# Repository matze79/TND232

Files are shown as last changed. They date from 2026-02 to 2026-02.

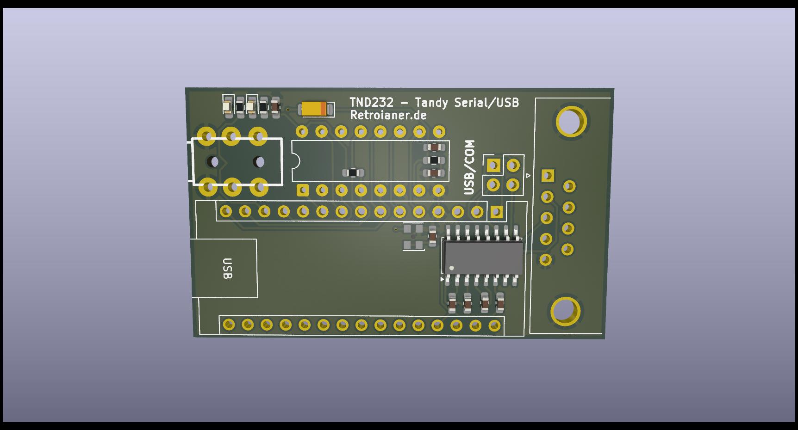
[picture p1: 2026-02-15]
Hardware/SMD/Tandy SMD.jpg

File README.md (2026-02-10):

📢 Project: TND232 – RS232 & USB SN76489 Tandy Sound Card

Home Project Site: https://www.retroianer.de

TND232 is a retro-computing hardware and software project to bring authentic Tandy/PCjr style 3-voice sound to IBM-PC compatible computers using modern interfaces like RS232 (serial) and USB, driven by the classic Texas Instruments SN76489 programmable sound generator chip.

🎯 Overview

Many classic DOS games support the Tandy 1000’s 3-voice audio produced by the SN76489 sound chip, but modern vintage add-ons like ISA boards aren’t always practical for newer PCs or laptops without expansion slots. The TND232 project provides an interface to control an SN76489 sound generator externally:

Serial (RS232) interface – connect via the PC’s COM port

USB interface – USB-powered control for systems without RS232

Drives an SN76489 sound module (3 square waves + noise) for authentic sound output on classic software

Includes DOS drivers/utilities to support music and game sound

The goal is to offer a flexible, cross-platform way to add real retro sound hardware to DOS machines without needing an ISA expansion card, while preserving authentic Tandy audio for games and demos.

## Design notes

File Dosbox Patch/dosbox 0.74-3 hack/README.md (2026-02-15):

DOSBox 0.74.3 – Serial Port Hack

This repository contains a modified File of DOSBox 0.74.3 with the serial device hardcoded in the source.

⚠️ Warning:

This is not a proper DOSBox serial implementation.

It is only a quick hack to make serial communication work in a limited way.

Serial Port Configuration

Edit the serial device directly in the source code.

Example devices:

Linux USB serial #1:

/dev/ttyUSB0

Adjust the device path as needed for your system.

Replace the modified file in the DOSBox 0.74.3 source tree.

Build \& Install

Install into a separate prefix to avoid conflicts.

./configure --prefix=/opt/dosbox-tandyserial

make

make install

Platform Status

NetBSD code - tested only on NetBSD 10.1 / sparc64 

Limitations

Experimental / hacky

Not upstream-ready

Minimal functionality only

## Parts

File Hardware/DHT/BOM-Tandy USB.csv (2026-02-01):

Comment | Designator | Footprint | LCSC | Quantity
2,2K | R4 | R_Axial_DIN0207_L6.3mm_D2.5mm_P10.16mm_Horizontal |  | 1
XO32 | Y3 | Oscillator_SMD_EuroQuartz_XO32-4Pin_3.2x2.5mm |  | 1
SG-7050CCN | Y2 | Oscillator_SMD_SeikoEpson_SG8002CA-4Pin_7.0x5.0mm |  | 1
DE9_Socket_MountingHoles | J3 | DSUB-9_Socket_Horizontal_P2.77x2.84mm_EdgePinOffset4.94mm_Housed_MountingHolesOffset4.94mm |  | 1
LED | D1 | LED_D3.0mm |  | 1
LED | D2 | LED_D3.0mm |  | 1
100nf | C9 | C_Disc_D3.4mm_W2.1mm_P2.50mm |  | 1
10uf | C6 | CP_Radial_D5.0mm_P2.50mm |  | 1
100nf | C8 | C_Disc_D3.4mm_W2.1mm_P2.50mm |  | 1
10uf | C7 | CP_Radial_D5.0mm_P2.50mm |  | 1
100nf | C2 | C_Disc_D3.4mm_W2.1mm_P2.50mm |  | 1
SN76489AN | U1 | DIP-16_W7.62mm |  | 1
10uf | C5 | CP_Radial_D5.0mm_P2.50mm |  | 1
3.579 Mhz | Y1 | Oscillator_DIP-14 |  | 1
10uf | C4 | CP_Radial_D5.0mm_P2.50mm |  | 1
33R | R1 | R_Axial_DIN0207_L6.3mm_D2.5mm_P10.16mm_Horizontal |  | 1
100uf | C3 | CP_Radial_D5.0mm_P2.50mm |  | 1
68pf | C1 | C_Disc_D3.4mm_W2.1mm_P2.50mm |  | 1
AudioJack3 | J1 | jack_3.5_pj313d-smt |  | 1
330R | R2 | R_Axial_DIN0207_L6.3mm_D2.5mm_P10.16mm_Horizontal |  | 1
330R | R3 | R_Axial_DIN0207_L6.3mm_D2.5mm_P10.16mm_Horizontal |  | 1
MAX232 | U2 | DIP-16_W7.62mm_LongPads |  | 1
Arduino_Nano_v3.x | A1 | Arduino_Nano |  | 1

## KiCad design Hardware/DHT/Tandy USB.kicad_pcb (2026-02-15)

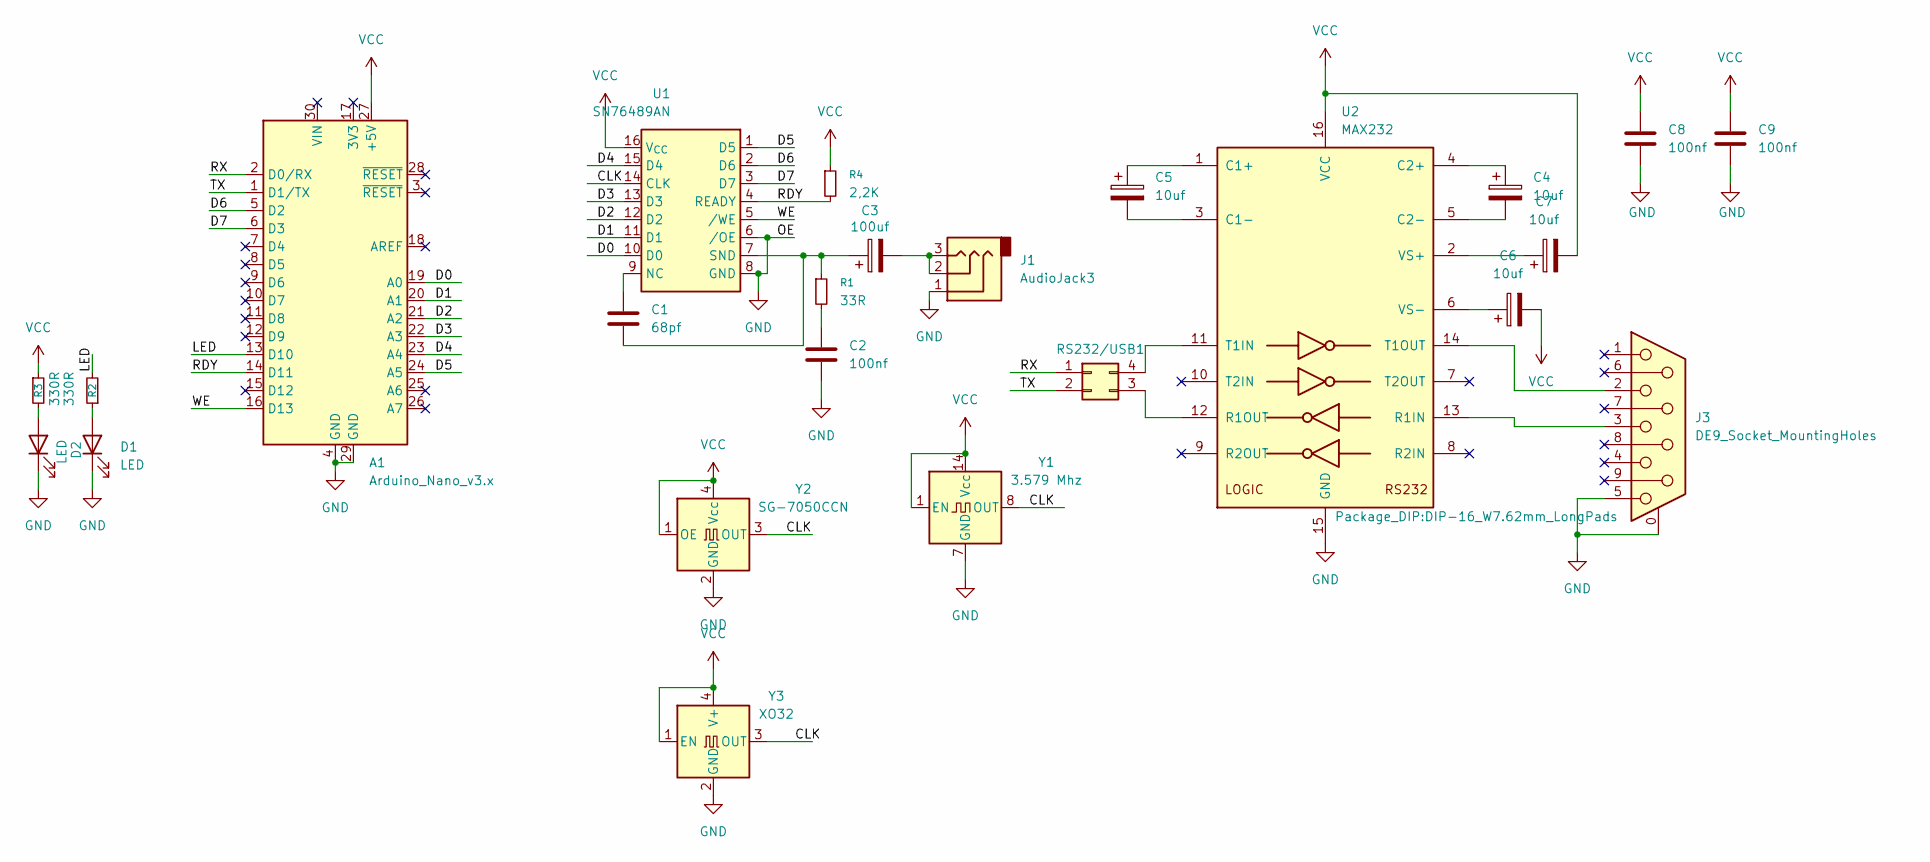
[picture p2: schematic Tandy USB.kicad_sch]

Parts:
A1: Arduino_Nano_v3.x; Arduino_Nano
C1: 68pf; C_Disc_D3.4mm_W2.1mm_P2.50mm
C2, C8, C9: 100nf; C_Disc_D3.4mm_W2.1mm_P2.50mm
C3: 100uf; CP_Radial_D5.0mm_P2.50mm
C4, C5, C6, C7: 10uf; CP_Radial_D5.0mm_P2.50mm
D1, D2: LED; LED_D3.0mm
J1: AudioJack3; jack_3.5_pj313d-smt
J3: DE9_Socket_MountingHoles; DSUB-9_Socket_Horizontal_P2.77x2.84mm_EdgePinOffset4.94mm_H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
R1: 33R; R_Axial_DIN0207_L6.3mm_D2.5mm_P10.16mm_Horizontal
R2, R3: 330R; R_Axial_DIN0207_L6.3mm_D2.5mm_P10.16mm_Horizontal
R4: 2,2K; R_Axial_DIN0207_L6.3mm_D2.5mm_P10.16mm_Horizontal
RS232/USB1: Conn_02x02_Counter_Clockwise; PinHeader_2x02_P2.54mm_Vertical
U1: SN76489AN; DIP-16_W7.62mm
U2: MAX232; DIP-16_W7.62mm_LongPads
Y1: 3.579 Mhz; Oscillator_DIP-14
Y2: SG-7050CCN; Oscillator_SMD_SeikoEpson_SG8002CA-4Pin_7.0x5.0mm
Y3: XO32; Oscillator_SMD_EuroQuartz_XO32-4Pin_3.2x2.5mm

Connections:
/CLK: U1.14 (CLK), Y1.8 (OUT), Y2.3 (OUT), Y3.3 (OUT)
/D0: A1.19 (A0), U1.10 (D0)
/D1: A1.20 (A1), U1.11 (D1)
/D2: A1.21 (A2), U1.12 (D2)
/D3: A1.22 (A3), U1.13 (D3)
/D4: A1.23 (A4), U1.15 (D4)
/D5: A1.24 (A5), U1.1 (D5)
/D6: A1.5 (D2), U1.2 (D6)
/D7: A1.6 (D3), U1.3 (D7)
/LED: A1.13 (D10), R2.2
/RDY: A1.14 (D11), R4.2, U1.4 (READY)
/RX: A1.2 (D0/RX), RS232/USB1.1
/TX: A1.1 (D1/TX), RS232/USB1.2
/WE: A1.16 (D13), U1.5 (/WE)
GND: A1.4 (GND), A1.29 (GND), C2.1, C8.1, C9.1, D1.1 (K), D2.1 (K), J1.1, J3.0 (PAD), J3.5, U1.6 (/OE), U1.8 (GND), U2.15 (GND), Y1.7 (GND), Y2.2 (GND), Y3.2 (GND)
unnamed: C2.2, R1.2
unnamed: C3.2, J1.2, J1.3
unnamed: D1.2 (A), R2.1
unnamed: D2.2 (A), R3.2
unnamed: RS232/USB1.3, U2.12 (R1OUT)
unnamed: RS232/USB1.4, U2.11 (T1IN)
unnamed: C1.2, U1.9 (NC)
unnamed: C1.1, C3.1, R1.1, U1.7 (SND)
unnamed: C5.1, U2.1 (C1+)
unnamed: C5.2, U2.3 (C1-)
unnamed: C4.1, U2.4 (C2+)
unnamed: C4.2, U2.5 (C2-)
unnamed: J3.3, U2.13 (R1IN)
unnamed: J3.2, U2.14 (T1OUT)
unnamed: C7.1, U2.2 (VS+)
unnamed: C6.1, U2.6 (VS-)
VCC: A1.27 (+5V), C6.2, C7.2, C8.2, C9.2, R3.1, R4.1, U1.16 (V_{CC}), U2.16 (VCC), Y1.1 (EN), Y1.14 (Vcc), Y2.1 (OE), Y2.4 (Vcc), Y3.1 (EN), Y3.4 (V+)

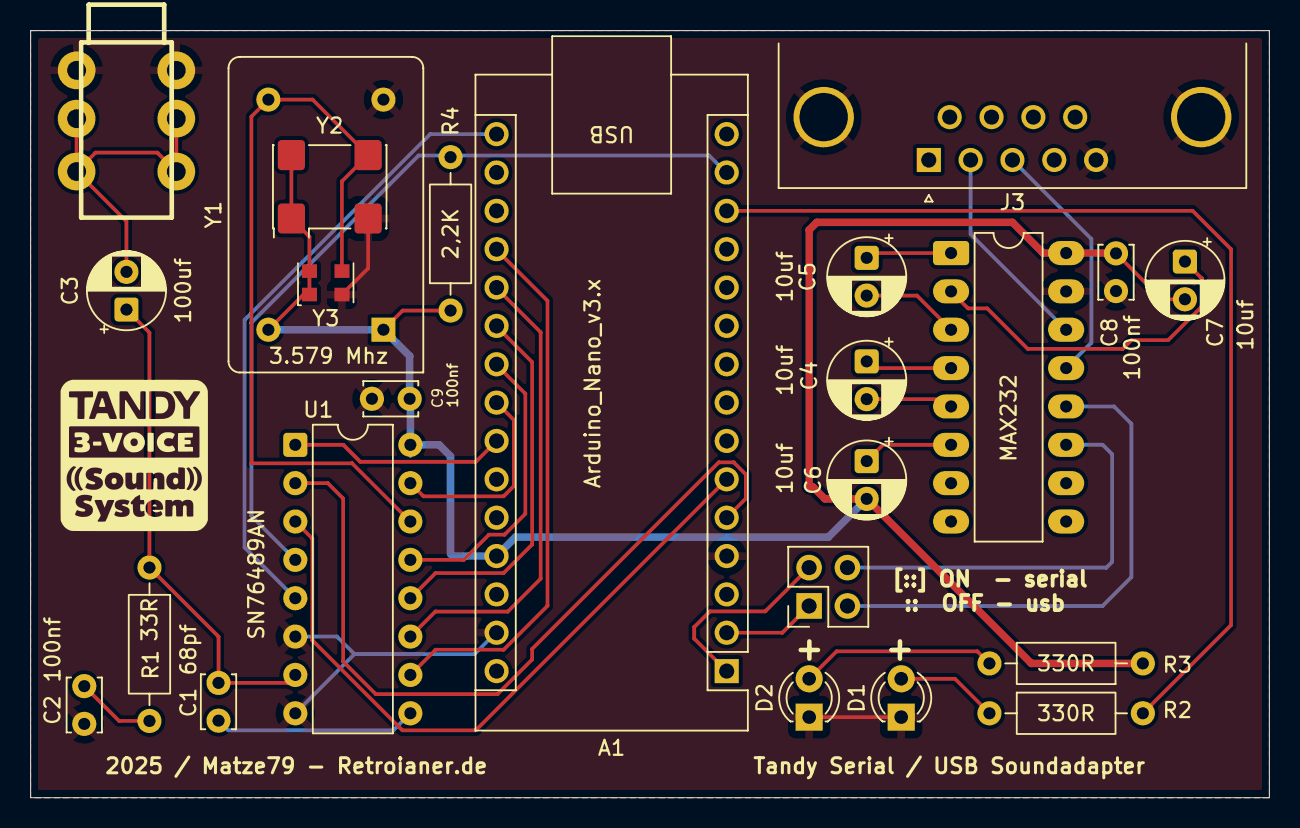
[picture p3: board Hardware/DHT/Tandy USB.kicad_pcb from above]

Board: 2 copper layers, 82.0 x 50.8 mm, 24 parts (0 on the bottom side), 32 nets.

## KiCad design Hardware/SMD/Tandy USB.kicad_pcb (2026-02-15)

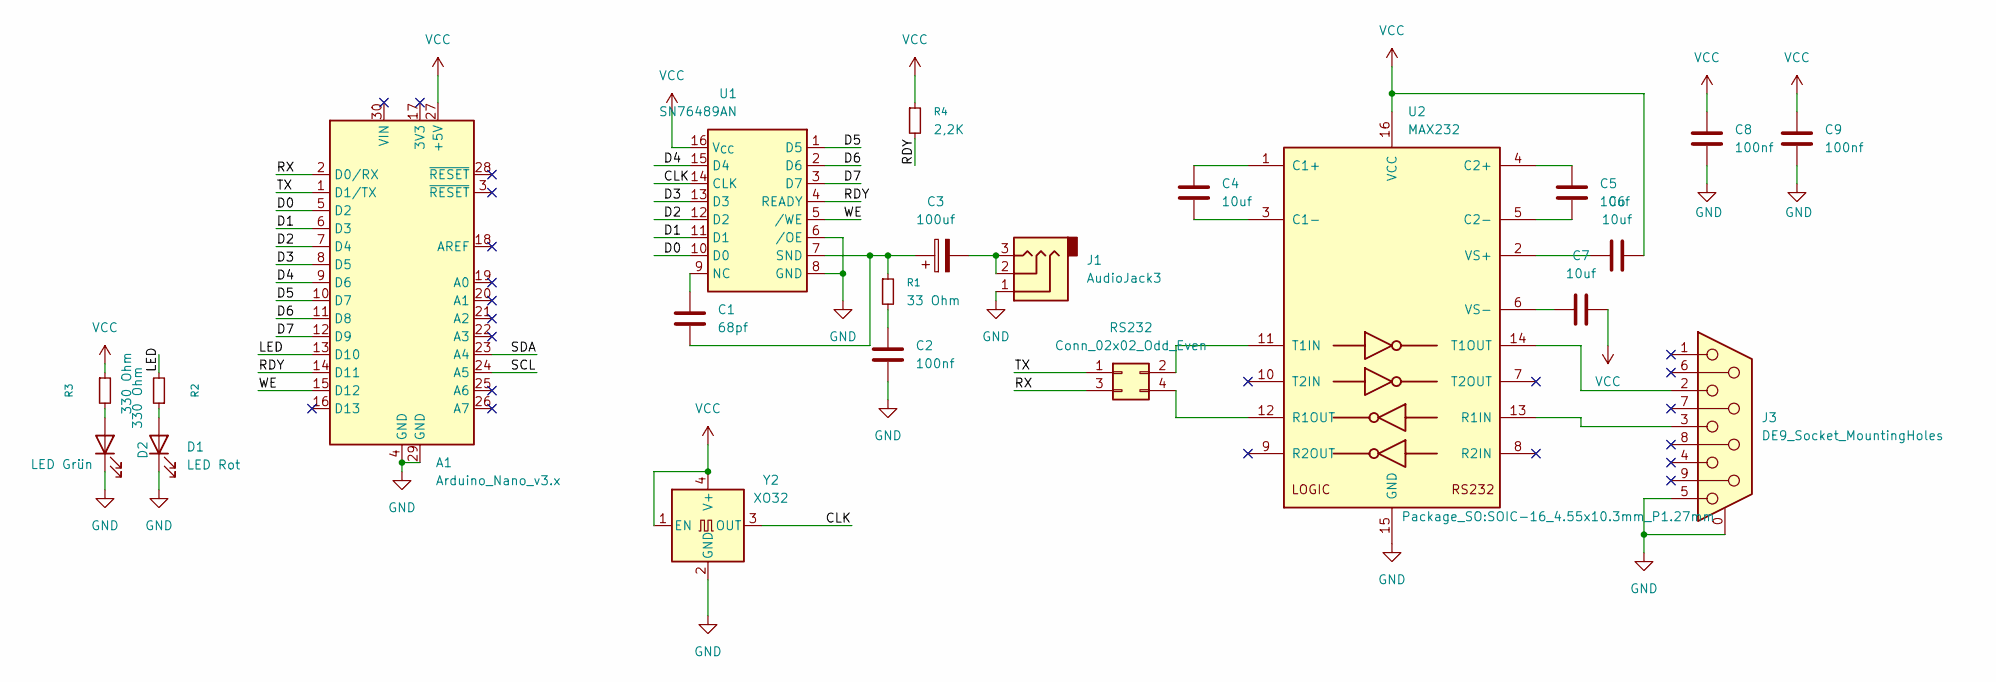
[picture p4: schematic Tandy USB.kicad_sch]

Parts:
A1: Arduino_Nano_v3.x; Arduino_Nano
C1: 68pf; C_0603_1608Metric_Pad1.08x0.95mm_HandSolder
C2, C8, C9: 100nf; C_0603_1608Metric_Pad1.08x0.95mm_HandSolder
C3: 100uf; CP_EIA-3216-10_Kemet-I_HandSolder
C4, C5, C6, C7: 10uf; C_0603_1608Metric_Pad1.08x0.95mm_HandSolder
D1: LED Rot; LED_0603_1608Metric_Pad1.05x0.95mm_HandSolder
D2: LED Grün; LED_0603_1608Metric_Pad1.05x0.95mm_HandSolder
J1: AudioJack3; jack_3.5_pj313d-smt
J3: DE9_Socket_MountingHoles; DSUB-9_Socket_Horizontal_P2.77x2.84mm_EdgePinOffset4.94mm_H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
R1: 33 Ohm; R_0603_1608Metric_Pad0.98x0.95mm_HandSolder
R2, R3: 330 Ohm; R_0603_1608Metric_Pad0.98x0.95mm_HandSolder
R4: 2,2K; R_0603_1608Metric_Pad0.98x0.95mm_HandSolder
RS232: Conn_02x02_Odd_Even; PinHeader_2x02_P2.54mm_Vertical
U1: SN76489AN; DIP-16_W7.62mm
U2: MAX232; SOIC-16_4.55x10.3mm_P1.27mm
Y2: XO32; Oscillator_SMD_EuroQuartz_XO32-4Pin_3.2x2.5mm

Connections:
/CLK: U1.14 (CLK), Y2.3 (OUT)
/D0: A1.5 (D2), U1.10 (D0)
/D1: A1.6 (D3), U1.11 (D1)
/D2: A1.7 (D4), U1.12 (D2)
/D3: A1.8 (D5), U1.13 (D3)
/D4: A1.9 (D6), U1.15 (D4)
/D5: A1.10 (D7), U1.1 (D5)
/D6: A1.11 (D8), U1.2 (D6)
/D7: A1.12 (D9), U1.3 (D7)
/LED: A1.13 (D10), R2.2
/RDY: A1.14 (D11), R4.2, U1.4 (READY)
/RX: A1.2 (D0/RX), RS232.3
/SCL: A1.24 (A5)
/SDA: A1.23 (A4)
/TX: A1.1 (D1/TX), RS232.1
/WE: A1.15 (D12), U1.5 (/WE)
GND: A1.4 (GND), A1.29 (GND), C2.1, C8.1, C9.1, D1.1 (K), D2.1 (K), J1.1, J3.0 (PAD), J3.5, U1.6 (/OE), U1.8 (GND), U2.15 (GND), Y2.2 (GND)
unnamed: C2.2, R1.2
unnamed: C3.2, J1.2, J1.3
unnamed: D1.2 (A), R2.1
unnamed: D2.2 (A), R3.2
unnamed: RS232.2, U2.11 (T1IN)
unnamed: RS232.4, U2.12 (R1OUT)
unnamed: C1.2, U1.9 (NC)
unnamed: C1.1, C3.1, R1.1, U1.7 (SND)
unnamed: C4.2, U2.1 (C1+)
unnamed: C4.1, U2.3 (C1-)
unnamed: C5.2, U2.4 (C2+)
unnamed: C5.1, U2.5 (C2-)
unnamed: J3.3, U2.13 (R1IN)
unnamed: J3.2, U2.14 (T1OUT)
unnamed: C6.2, U2.2 (VS+)
unnamed: C7.2, U2.6 (VS-)
VCC: A1.27 (+5V), C6.1, C7.1, C8.2, C9.2, R3.1, R4.1, U1.16 (V_{CC}), U2.16 (VCC), Y2.1 (EN), Y2.4 (V+)

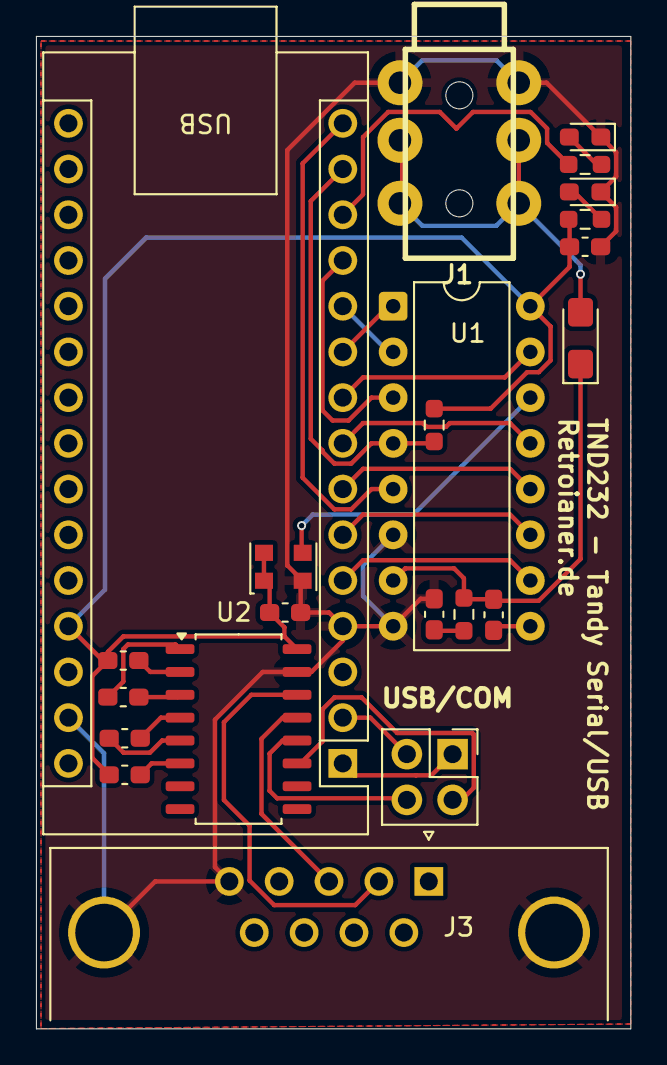
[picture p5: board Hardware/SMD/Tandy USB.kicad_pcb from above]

Board: 2 copper layers, 33.0 x 55.1 mm, 22 parts (0 on the bottom side), 32 nets.

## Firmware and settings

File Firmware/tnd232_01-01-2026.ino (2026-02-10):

// matze79 - 01-01-2026

#define USE_PINSET_A 1
//#define USE_PINSET_A 0

#if USE_PINSET_A

// SMD Version
#define WE     12
#define LED    10
#define PIN_D0 2
#define PIN_D1 3
#define PIN_D2 4
#define PIN_D3 5
#define PIN_D4 6
#define PIN_D5 7
#define PIN_D6 8
#define PIN_D7 9

#else

// DHT Version
#define WE     13
#define LED    10
#define PIN_D0 14
#define PIN_D1 15
#define PIN_D2 16
#define PIN_D3 17
#define PIN_D4 18
#define PIN_D5 19
#define PIN_D6 2
#define PIN_D7 3

#endif
unsigned long lastSerialActivity = 0;
unsigned long ledOnUntil = 0;
bool muted = false;

const unsigned long IDLE_TIMEOUT_MS = 1000;
const unsigned long LED_ACTIVITY_MS = 120;

void SendByteToSoundChip(byte b)
{
  digitalWrite(PIN_D0, (b & 1)   ? HIGH : LOW);
  digitalWrite(PIN_D1, (b & 2)   ? HIGH : LOW);
  digitalWrite(PIN_D2, (b & 4)   ? HIGH : LOW);
  digitalWrite(PIN_D3, (b & 8)   ? HIGH : LOW);
  digitalWrite(PIN_D4, (b & 16)  ? HIGH : LOW);
  digitalWrite(PIN_D5, (b & 32)  ? HIGH : LOW);
  digitalWrite(PIN_D6, (b & 64)  ? HIGH : LOW);
  digitalWrite(PIN_D7, (b & 128) ? HIGH : LOW);

  digitalWrite(WE, LOW);
  delayMicroseconds(5);   // stabiler als delay(1)
  digitalWrite(WE, HIGH);
}

void SilenceAllChannels()
{
  // NUR EINMAL, nie im Datenstrom
  SendByteToSoundChip(0x9F);
  SendByteToSoundChip(0xBF);
  SendByteToSoundChip(0xDF);
  SendByteToSoundChip(0xFF);
}

void setup()
{
  pinMode(WE, OUTPUT);
  digitalWrite(WE, HIGH);
 
  pinMode(PIN_D0, OUTPUT);
  pinMode(PIN_D1, OUTPUT);
  pinMode(PIN_D2, OUTPUT);
  pinMode(PIN_D3, OUTPUT);
  pinMode(PIN_D4, OUTPUT);
  pinMode(PIN_D5, OUTPUT);
  pinMode(PIN_D6, OUTPUT);
  pinMode(PIN_D7, OUTPUT);

  pinMode(LED, OUTPUT);
  digitalWrite(LED, LOW);
  PlayJingle();

  Serial.begin(115200);
  lastSerialActivity = millis();
}

void SendTone(byte channel, int frequency, byte volume) {
  if (frequency == 0) { // Silence
    SendByteToSoundChip(0x90 | (channel << 5) | 0x0F); // Mute
    return;
  }

  int N = 3579545 / (32 * frequency); // SN76489 frequency formula
  byte lsb = N & 0x0F;
  byte msb = (N >> 4) & 0x3F;

  // Tone register
  SendByteToSoundChip(0x80 | (channel << 5) | lsb); // LSB
  SendByteToSoundChip(msb);                         // MSB

  // Volume register (0=full, 15=silent)
  SendByteToSoundChip(0x90 | (channel << 5) | (15 - volume));
}

void PlayJingle() {
  // C-Dur Tonleiter
  const int freq[] = {
    262,  // C4
    294,  // D4
    330,  // E4
    349,  // F4
    392,  // G4
    440,  // A4
    494,  // B4
    523   // C5
  };

  const int noteCount = sizeof(freq) / sizeof(freq[0]);

  SilenceAllChannels();

  for (int i = 0; i < noteCount; i++) {

    byte channel = i % 3;   // 0,1,2

    int N = 3579545 / (32 * freq[i]);

    byte lsb = N & 0x0F;
    byte msb = (N >> 4) & 0x3F;

    // --- Tone latch (LSB) ---
    SendByteToSoundChip(0x80 | (channel << 5) | lsb);

    // --- Tone MSB ---
    SendByteToSoundChip(msb);

    // --- Volume (0 = laut) ---
    SendByteToSoundChip(0x90 | (channel << 5) | 0x00);
    
    delay(300);
   }
  SilenceAllChannels();
}


void loop()
{
  // --- KRITISCHER PFAD ---
  while (Serial.available() > 0) {
    byte b = Serial.read();
    SendByteToSoundChip(b);

    lastSerialActivity = millis();
    ledOnUntil = lastSerialActivity + LED_ACTIVITY_MS;
    muted = false;
  }

  // --- UNKRITISCHER PFAD ---
  unsigned long now = millis();

  // LED nur zeitgesteuert, kein Einfluss auf RX
  if (now < ledOnUntil) {
    digitalWrite(LED, HIGH);
  } else {
    digitalWrite(LED, LOW);
  }

  // Idle-Mute nur wenn WIRKLICH ruhig
  if (!muted && (now - lastSerialActivity > IDLE_TIMEOUT_MS)) {
    SilenceAllChannels();
    muted = true;
  }
}

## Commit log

2026-01-31 TND232 Driver
    Tandy Serial Soundcard Driver
2026-01-31 Add project description for TND232 serial driver
2026-02-01 PCB Files
    PCB Gerbers for Tandy DHT Variant
    [BOM-Tandy USB.csv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]
2026-02-15 PCB Files / Gerbers
    PCB Files and Gerbers added
    [Tandy USB.kicad_pcb, Tandy USB.kicad_sch]
2026-02-15 PCB Picture
    Added Picture
